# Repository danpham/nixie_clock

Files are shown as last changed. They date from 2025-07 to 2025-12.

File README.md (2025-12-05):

# Nixie Clock ESP32-C3

A **Nixie tube clock project** based on the **ESP32-C3**, using **IN14** and **IN3** tubes driven by **HV5622** high-voltage drivers.

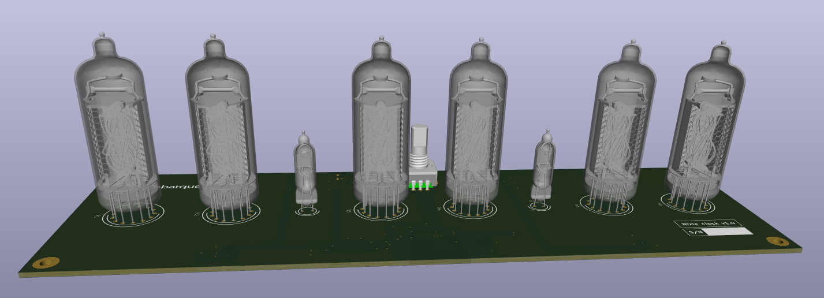
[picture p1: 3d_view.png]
3D View


## Hardware

- **Microcontroller:** ESP32-C3  
- **Nixie tubes:** 6 × IN14 and 2 × IN3  
- **Driver:** HV5622 for cathode switching  
- **Rotary encoder:** EC11 for time configuration  
- **3.3V regulator:** AP63203WU to power the ESP32-C3 and logic components  
- **PCB design:** SMD (Surface-Mount) components

> [!WARNING]
> This project involves high voltage. Follow proper electrical safety procedures!

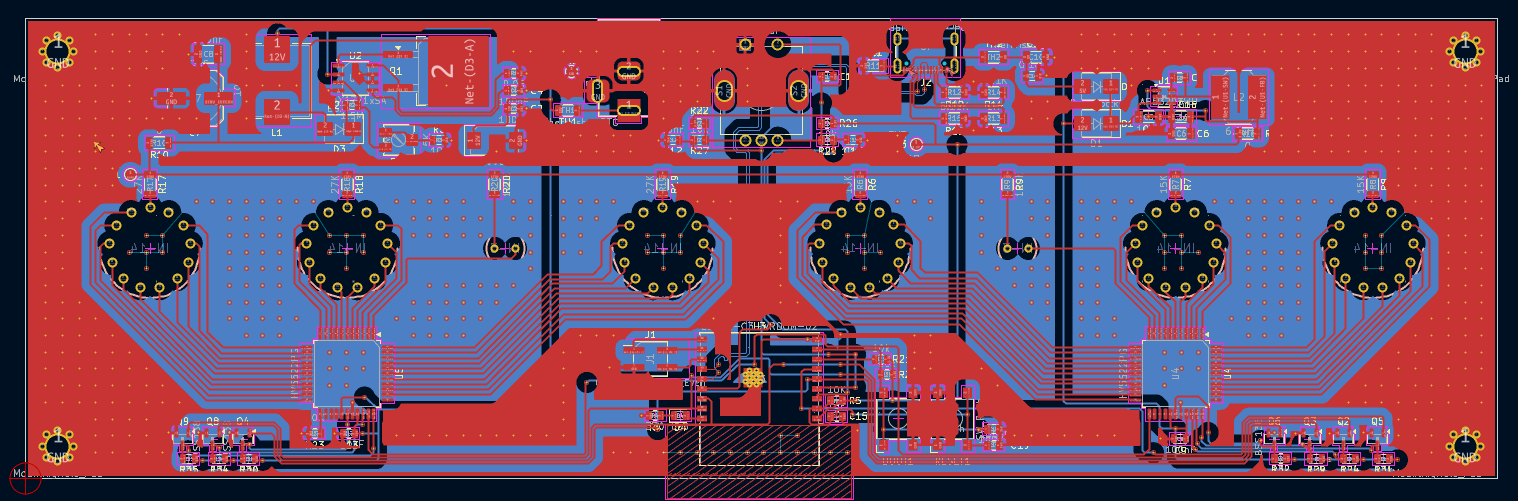
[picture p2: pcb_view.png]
PCB Back


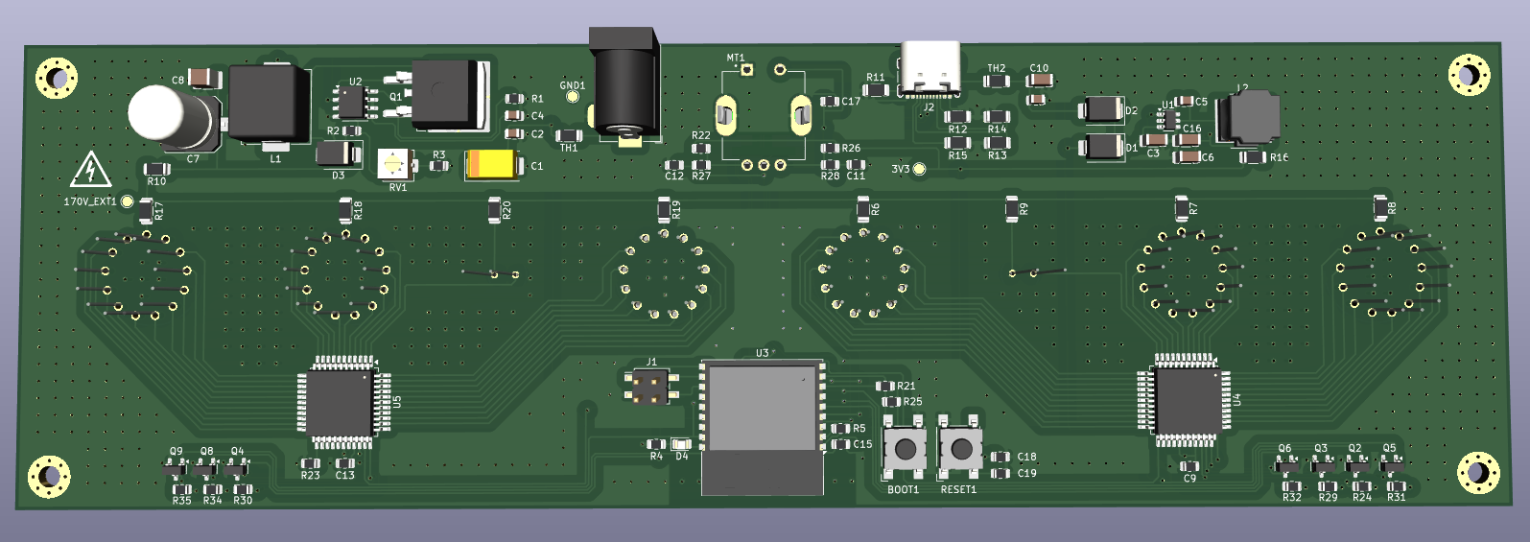
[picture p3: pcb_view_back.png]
PCB Back 3D


## Software

The code is written in **C for the ESP32-C3**, organized as follows:

```
software/nixie_clock_esp32_project/
├── components/
│   ├── uart/
│   ├── gpio_driver/
│   ├── display/
│   ├── clock/
│   └── hv5622/
└── main/
```

### Current Features

- Nixie tube display control via HV5622  
- Rotary encoder input (EC11) for setting the time  
- Internal clock management  
- **Anti–cathode poisoning routine:** periodic cycling and cathode management to prevent oxide buildup and extend tube lifespan  

### Future Features

- Wi-Fi connectivity for automatic time synchronization  
- Web interface for configuration: timezone, brightness, night mode, and display enable/disable  

## Compilation

The project uses **ESP-IDF for ESP32-C3**. Make sure your ESP32-C3 development environment is properly set up.

```bash
cd software/nixie_clock_esp32_project
idf.py build
idf.py flash
```

## Test

### Unit testing

In ESP-IDF terminal:
```bash
cd software/nixie_clock_esp32_project/test/unit
cmake -S . -B build
cmake --build build --config Release
.\build\Release\native_tests.exe
```

### Integration testing

In ESP-IDF terminal:
```bash
cd software/nixie_clock_esp32_project/test/integration
cmake -S . -B build
cmake --build build --config Release
.\build\Release\native_integration_tests.exe
```

## License

This project is released under the **GPL v3** license.  
A separate `LICENSE` file contains the complete text of the license.

## Safety

> [!WARNING]
> This project involves **high voltage (~170V for Nixie tubes)**.  
> Never touch the circuit while it is powered
> Work carefully and only with proper knowledge of high-voltage electronics

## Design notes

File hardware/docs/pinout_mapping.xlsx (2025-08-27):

Shifts | HV_* | Nixie | Data
0 | HV1_1 | N3_DOT
1 | HV1_2 | N3_0 | minute_hi
2 | HV1_3 | N3_9 | minute_hi
3 | HV1_4 | N3_8 | minute_hi
4 | HV1_5 | N3_7 | minute_hi
5 | HV1_6 | N3_6 | minute_hi
6 | HV1_7 | N3_5 | minute_hi
7 | HV1_8 | N3_4 | minute_hi
8 | HV1_9 | N3_3 | minute_hi
9 | HV1_10 | N3_2 | minute_hi
10 | HV1_11 | N3_1 | minute_hi
11 | HV1_12 | DOT1
12 | HV1_13 | N2_0 | hour_lo
13 | HV1_14 | N2_9 | hour_lo
14 | HV1_15 | N2_8 | hour_lo
15 | HV1_16 | N2_7 | hour_lo
16 | HV1_17 | N2_6 | hour_lo
17 | HV1_18 | N2_5 | hour_lo
18 | HV1_19 | N2_4 | hour_lo
19 | HV1_20 | N2_3 | hour_lo
20 | HV1_21 | N2_2 | hour_lo
21 | HV1_22 | N2_1 | hour_lo
22 | HV1_23 | N1_0 | hour_hi
23 | HV1_24 | N1_9 | hour_hi
24 | HV1_25 | N1_8 | hour_hi
25 | HV1_26 | N1_7 | hour_hi
26 | HV1_27 | N1_6 | hour_hi
27 | HV1_28 | N1_5 | hour_hi
28 | HV1_29 | N1_4 | hour_hi
29 | HV1_30 | N1_3 | hour_hi
30 | HV1_31 | N1_2 | hour_hi
31 | HV1_32 | N1_1 | hour_hi
32 | HV2_1 | N6_DOT
33 | HV2_2 | N6_0 | second_low
34 | HV2_3 | N6_9 | second_low
35 | HV2_4 | N6_8 | second_low
36 | HV2_5 | N6_7 | second_low
37 | HV2_6 | N6_6 | second_low
38 | HV2_7 | N6_5 | second_low
39 | HV2_8 | N6_4 | second_low
40 | HV2_9 | N6_3 | second_low
41 | HV2_10 | N6_2 | second_low
42 | HV2_11 | N6_1 | second_low
43 | HV2_12 | N5_0 | second_hi
44 | HV2_13 | N5_9 | second_hi
45 | HV2_14 | N5_8 | second_hi
46 | HV2_15 | N5_7 | second_hi
47 | HV2_16 | N5_6 | second_hi
48 | HV2_17 | N5_5 | second_hi
49 | HV2_18 | N5_4 | second_hi
50 | HV2_19 | N5_3 | second_hi
51 | HV2_20 | N5_2 | second_hi
52 | HV2_21 | N5_1 | second_hi
53 | HV2_22 | DOT2
54 | HV2_23 | N4_0 | minute_lo
55 | HV2_24 | N4_9 | minute_lo
56 | HV2_25 | N4_8 | minute_lo
57 | HV2_26 | N4_7 | minute_lo
58 | HV2_27 | N4_6 | minute_lo
59 | HV2_28 | N4_5 | minute_lo
60 | HV2_29 | N4_4 | minute_lo
61 | HV2_30 | N4_3 | minute_lo
62 | HV2_31 | N4_2 | minute_lo
63 | HV2_32 | N4_1 | minute_lo

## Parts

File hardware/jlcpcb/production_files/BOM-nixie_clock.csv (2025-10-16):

Comment | Designator | Footprint | LCSC | Quantity
Barrel_Jack_Switch | J7 | BarrelJack_Horizontal | C111567 | 1
1.5M | R2 | R_0805_2012Metric | C118025 | 1
100uF | C1 | CP_EIA-7343-31_Kemet-D_HandSolder | C122302 | 1
100nF | C13,C9 | R_0805_2012Metric | C126469 | 2
22uF | C16,C6 | C_1206_3216Metric | C12891 | 2
10uF | C10,C3 | C_1206_3216Metric | C13585 | 2
5.11K | R14,R15 | R_1206_3216Metric | C137249 | 2
PEC11R-4215F-S0024 | MT1 | XDCR_PEC11R-4215F-S0024 | C143790 | 1
ES2F | D3 | D_SMB | C145321 | 1
15K | R6,R7,R8 | R_1206_3216Metric | C1493 | 3
10k | R21,R22,R26,R27,R28,R5 | R_0805_2012Metric | C17414 | 6
330 | R4 | R_0805_2012Metric | C17630 | 1
0 | R10,R16 | R_1206_3216Metric | C17888 | 2
10K | R23,R25 | R_0805_2012Metric | C17902 | 2
120K | R20,R9 | R_1206_3216Metric | C17908 | 2
1M | R11,R12,R13 | R_1206_3216Metric | C17927 | 3
27K | R17,R18,R19 | R_1206_3216Metric | C17943 | 3
HV5622PG | U4,U5 | PQFP-44_10x10mm_P0.8mm | C220637 | 2
0.05 | R1 | R_0805_2012Metric | C247602 | 1
D_Schottky | D2 | D_SMB | C2479 | 1
D_Schottky | D1 | D_SMB | C2480 | 1
10k | R3 | R_0805_2012Metric | C269724 | 1
6.8uH | L2 | L_Bourns_SRN8040TA | C2849553 | 1
USB_C_Receptacle_USB2.0_16P | J2 | USB_C_Receptacle_GCT_USB4105-xx-A_16P_TopMnt_Horizontal | C2894897 | 1
ESP32-C3-WROOM-02 | U3 | ESP32-C3-WROOM-02 | C2934560 | 1
100uH | L1 | L_APV_APH1050 | C2962892 | 1
IRF740 | Q1 | TO-263-2 | C39238 | 1
0.1 uF | C14,C2,C4,C5 | C_0805_2012Metric | C396718 | 4
MAX1771xSA | U2 | SO-8_3.9x4.9mm_P1.27mm | C407903 | 1
100nF | C8 | C_1210_3225Metric_Pad1.33x2.70mm_HandSolder | C52020 | 1
Thermistor_PTC | TH1 | R_1206_3216Metric | C5678440 | 1
5K | RV1 | Potentiometer_Bourns_3314J_Vertical | C58391 | 1
AP63203WU | U1 | TSOT-23-6 | C780769 | 1
Thermistor_PTC | TH2 | R_1206_3216Metric | C883122 | 1
4.7uF | C7 | C_Elec_8x10.2 | C88702 | 1
Conn_02x02_Odd_Even | J1 | PinHeader_2x02_P2.54mm_Vertical_SMD | C919361 | 1
LED | D4 | LED_0805_2012Metric | C965812 | 1
TestPoint | GND1 | TestPoint_Pad_D1.5mm |  | 1
TestPoint | 3V3 | TestPoint_Pad_D1.5mm |  | 1
1uF | C15 | R_0805_2012Metric |  | 1
IN-14 | N6 | nixies-us-IN-14 |  | 1
IN-3 | DOT1 | nixies-us-IN-3 |  | 1
IN-14 | N3 | nixies-us-IN-14 |  | 1
IN-3 | DOT2 | nixies-us-IN-3 |  | 1
IN-14 | N1 | nixies-us-IN-14 |  | 1
IN-14 | N4 | nixies-us-IN-14 |  | 1
IN-14 | N5 | nixies-us-IN-14 |  | 1
IN-14 | N2 | nixies-us-IN-14 |  | 1
TestPoint | 170V_EXT1 | TestPoint_Pad_D1.5mm |  | 1
10nF | C12 | R_0805_2012Metric |  | 1
10nF | C11 | R_0805_2012Metric |  | 1
SW_Push | BOOT1 | SW_SPST_Omron_B3FS-100xP |  | 1
100nF | C18 | R_0805_2012Metric |  | 1
SW_Push | RESET1 | SW_SPST_Omron_B3FS-100xP |  | 1
100nf | C19 | R_0805_2012Metric |  | 1
100nF | C17 | R_0805_2012Metric |  | 1

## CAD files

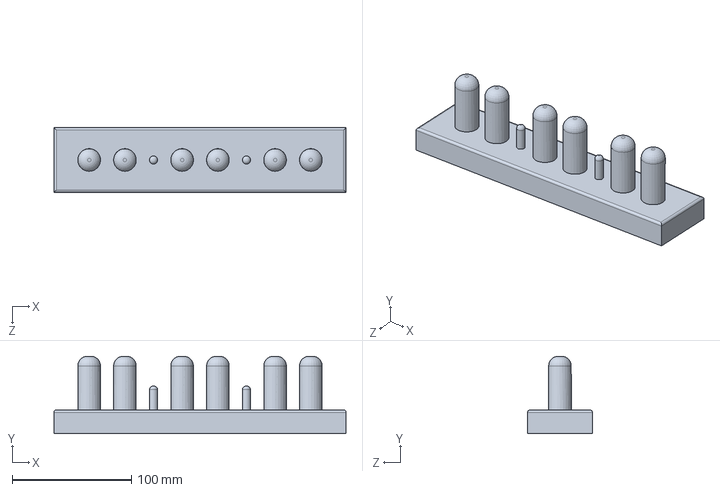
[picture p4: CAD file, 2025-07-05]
hardware/3d/nixie_clock.SLDPRT
245.0 x 65.0 x 54.3 mm

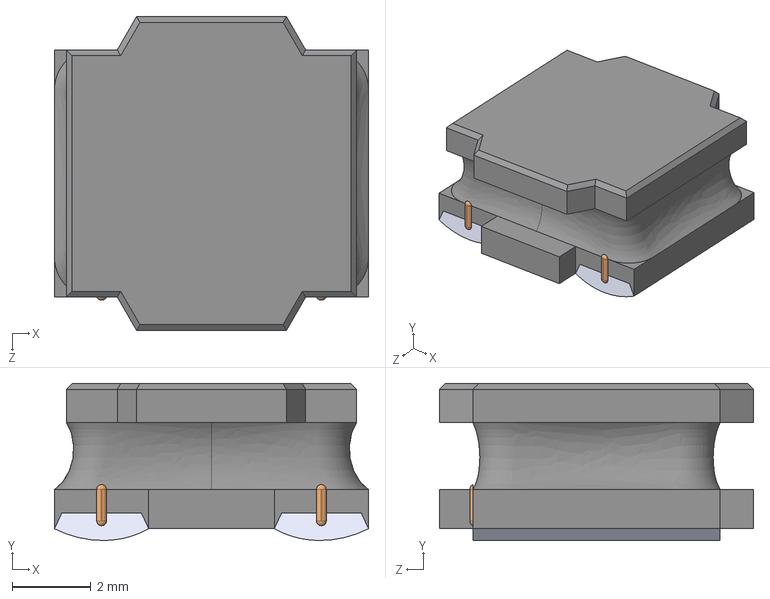
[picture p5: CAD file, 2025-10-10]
hardware/components/L_Bourns_SRN8040TA/L_Bourns_SRN8040TA.step
8.00 x 4.00 x 8.00 mm

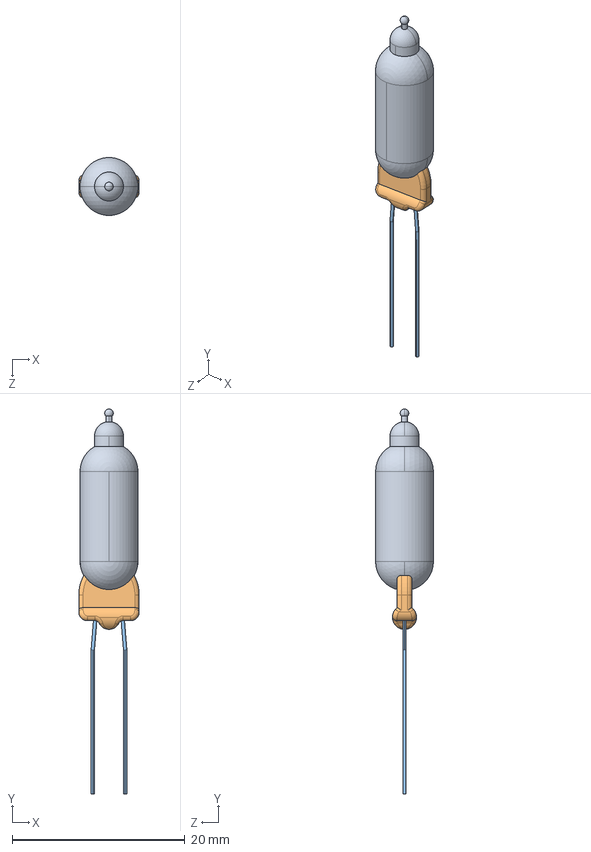
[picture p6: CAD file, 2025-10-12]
hardware/components/Nixies/NX-SZP-IN3-v01.STEP
7.00 x 44.6 x 6.70 mm
NX-SZP-IN3-01-v01
NX-SZP-IN3-02-v01 x 2
NX-SZP-IN3-03-v01
NX-SZP-IN3-04-v01
NX-SZP-IN3-05-v01
NX-SZP-IN3-06-v01

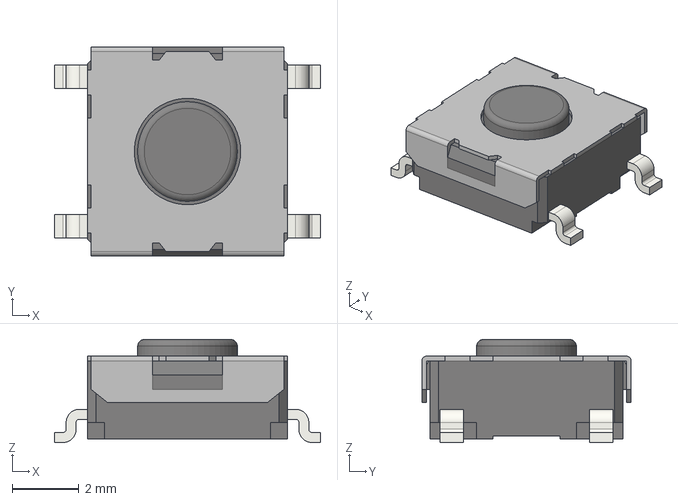
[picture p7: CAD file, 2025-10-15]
hardware/components/Omron_B3FS-1000P/SW_SPST_Omron_B3FS-100xP.step
8.00 x 6.30 x 3.10 mm

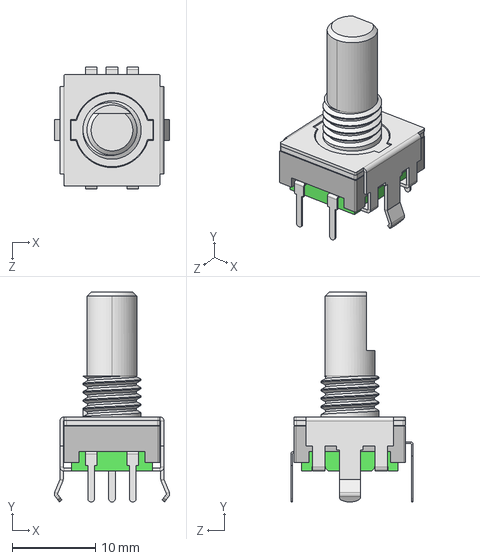
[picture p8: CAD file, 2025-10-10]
hardware/components/PEC11R-4215F-S0024/PEC11R-4215F-S0024.step
13.9 x 25.2 x 14.7 mm

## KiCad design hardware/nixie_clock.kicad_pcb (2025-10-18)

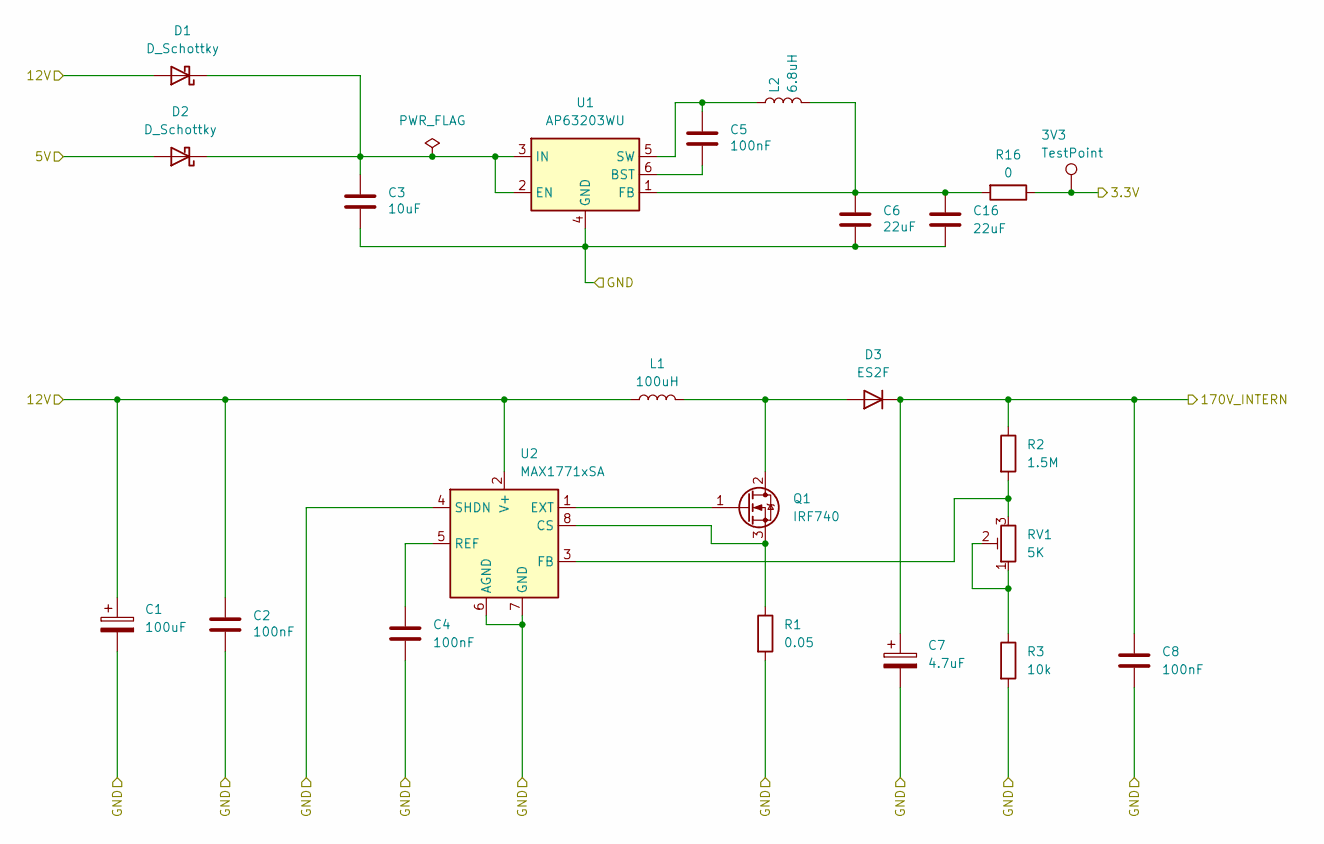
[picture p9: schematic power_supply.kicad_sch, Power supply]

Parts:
3V3: TestPoint; TestPoint_Pad_D1.5mm
C1: 100uF; CP_EIA-7343-31_Kemet-D_HandSolder
C2, C4, C5: 100nF; C_0805_2012Metric
C3: 10uF; C_1206_3216Metric
C6, C16: 22uF; C_1206_3216Metric
C7: 4.7uF; C_Elec_8x10.2
C8: 100nF; C_1210_3225Metric_Pad1.33x2.70mm_HandSolder
D1, D2: D_Schottky; D_SMB
D3: ES2F; D_SMB
L1: 100uH; L_APV_APH1050
L2: 6.8uH; L_Bourns_SRN8040TA
Q1: IRF740; TO-263-2
R1: 0.05; R_0805_2012Metric
R2: 1.5M; R_0805_2012Metric
R3: 10k; R_0805_2012Metric
R16: 0; R_1206_3216Metric
RV1: 5K; Potentiometer_Bourns_3314J_Vertical
U1: AP63203WU; TSOT-23-6
U2: MAX1771xSA; SO-8_3.9x4.9mm_P1.27mm

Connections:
/connectors/5V: D2.2 (A); also elsewhere on the board
/connectors/12V: C1.1, C2.1, D1.2 (A), L1.1, U2.2 (V+); also elsewhere on the board
/connectors/GND: C1.2, C2.2, C3.2, C4.2, C6.2, C7.2, C8.2, C16.2, R1.2, R3.2, U1.4 (GND), U2.4 (SHDN), U2.6 (AGND), U2.7 (GND); also elsewhere on the board
/cpu/3.3V: 3V3.1, R16.1; also elsewhere on the board
/driver_3_digits_1_dot_left/170V_INTERN: C7.1, C8.1, D3.1 (K), R2.1; also elsewhere on the board
unnamed: C3.1, D1.1 (K), D2.1 (K), U1.2 (EN), U1.3 (IN)
unnamed: D3.2 (A), L1.2, Q1.2 (D)
unnamed: Q1.1 (G), U2.1 (EXT)
unnamed: Q1.3 (S), R1.1, U2.8 (CS)
unnamed: R3.1, RV1.1, RV1.2
unnamed: C5.2, U1.6 (BST)
unnamed: C6.1, C16.1, L2.2, R16.2, U1.1 (FB)
unnamed: C5.1, L2.1, U1.5 (SW)
unnamed: R2.2, RV1.3, U2.3 (FB)
unnamed: C4.1, U2.5 (REF)

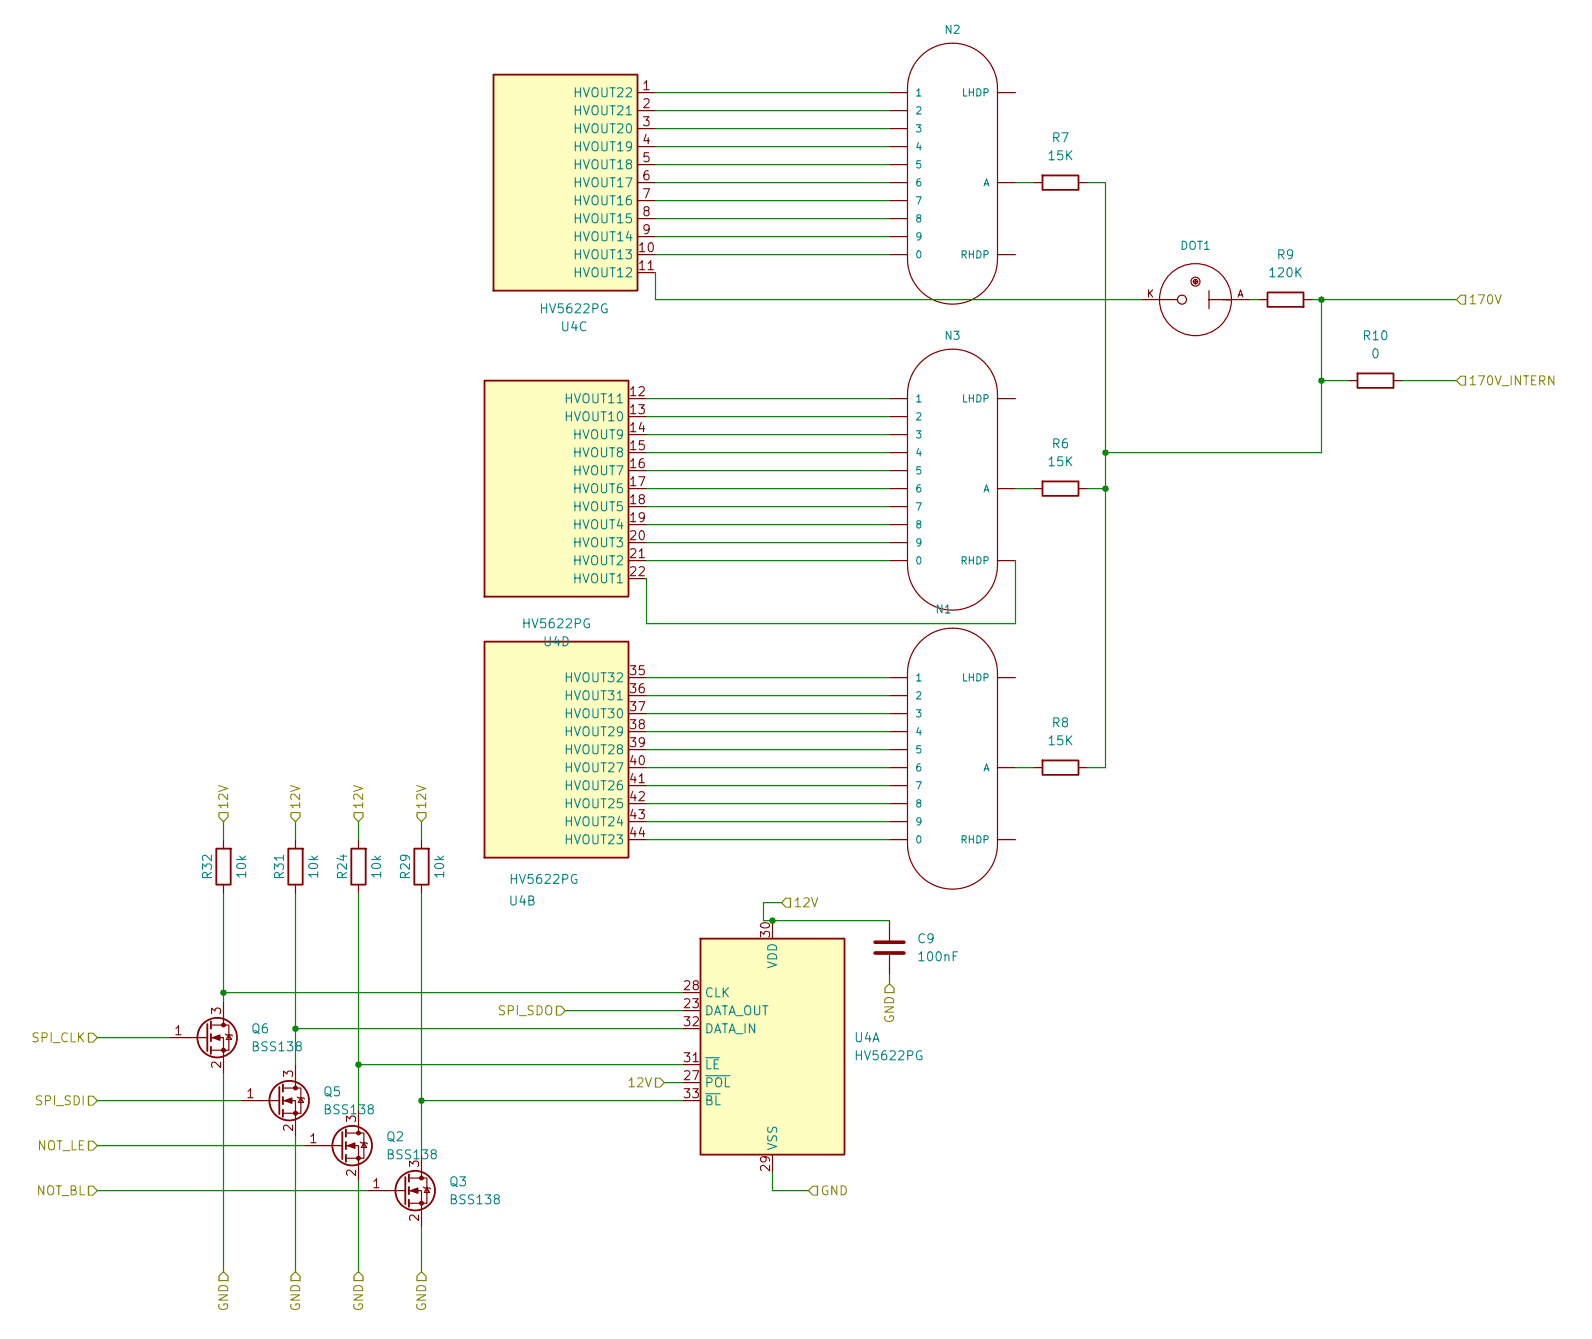
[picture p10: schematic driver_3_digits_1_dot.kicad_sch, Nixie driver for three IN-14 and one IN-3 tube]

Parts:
C9: 100nF; R_0805_2012Metric
DOT1: IN-3; nixies-us-IN-3
N1, N2, N3: IN-14; nixies-us-IN-14
Q2, Q3, Q5, Q6: BSS138; SOT-23
R6, R7, R8: 15K; R_1206_3216Metric
R9: 120K; R_1206_3216Metric
R10: 0; R_1206_3216Metric
R24, R29, R31, R32: 10k; R_0805_2012Metric
U4: HV5622PG; PQFP-44_10x10mm_P0.8mm

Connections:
/connectors/12V: C9.2, R24.2, R29.2, R31.2, R32.2, U4.27 (~POL), U4.30 (VDD); also elsewhere on the board
/connectors/170V: R6.1, R7.1, R8.1, R9.2, R10.2; also elsewhere on the board
/connectors/GND: C9.1, Q2.2 (S), Q3.2 (S), Q5.2 (S), Q6.2 (S), U4.29 (VSS); also elsewhere on the board
/cpu/GPIO1: Q3.1 (G); also elsewhere on the board
/cpu/GPIO2: Q2.1 (G); also elsewhere on the board
/cpu/SPI_CLK: Q6.1 (G); also elsewhere on the board
/cpu/SPI_MOSI: Q5.1 (G); also elsewhere on the board
/driver_3_digits_1_dot_left/170V_INTERN: R10.1; also elsewhere on the board
/driver_3_digits_1_dot_left/SPI_SDO: U4.23 (DATA_OUT); also elsewhere on the board
unnamed: DOT1.A, R9.1
unnamed: N1.A, R8.2
unnamed: N2.A, R7.2
unnamed: N3.A, R6.2
unnamed: Q2.3 (D), R24.1, U4.31 (~LE)
unnamed: Q3.3 (D), R29.1, U4.33 (~BL)
unnamed: Q5.3 (D), R31.1, U4.32 (DATA_IN)
unnamed: Q6.3 (D), R32.1, U4.28 (CLK)
unnamed: N1.0, U4.44 (HVOUT23)
unnamed: N1.9, U4.43 (HVOUT24)
unnamed: N1.8, U4.42 (HVOUT25)
unnamed: N1.7, U4.41 (HVOUT26)
unnamed: N1.6, U4.40 (HVOUT27)
unnamed: N1.5, U4.39 (HVOUT28)
unnamed: N1.4, U4.38 (HVOUT29)
unnamed: N1.3, U4.37 (HVOUT30)
unnamed: N1.2, U4.36 (HVOUT31)
unnamed: N1.1, U4.35 (HVOUT32)
unnamed: DOT1.K, U4.11 (HVOUT12)
unnamed: N2.0, U4.10 (HVOUT13)
unnamed: N2.9, U4.9 (HVOUT14)
unnamed: N2.8, U4.8 (HVOUT15)
unnamed: N2.7, U4.7 (HVOUT16)
unnamed: N2.6, U4.6 (HVOUT17)
unnamed: N2.5, U4.5 (HVOUT18)
unnamed: N2.4, U4.4 (HVOUT19)
unnamed: N2.3, U4.3 (HVOUT20)
unnamed: N2.2, U4.2 (HVOUT21)
unnamed: N2.1, U4.1 (HVOUT22)
unnamed: N3.RHDP, U4.22 (HVOUT1)
unnamed: N3.0, U4.21 (HVOUT2)
unnamed: N3.9, U4.20 (HVOUT3)
unnamed: N3.8, U4.19 (HVOUT4)
unnamed: N3.7, U4.18 (HVOUT5)
unnamed: N3.6, U4.17 (HVOUT6)
unnamed: N3.5, U4.16 (HVOUT7)
unnamed: N3.4, U4.15 (HVOUT8)
unnamed: N3.3, U4.14 (HVOUT9)
unnamed: N3.2, U4.13 (HVOUT10)
unnamed: N3.1, U4.12 (HVOUT11)

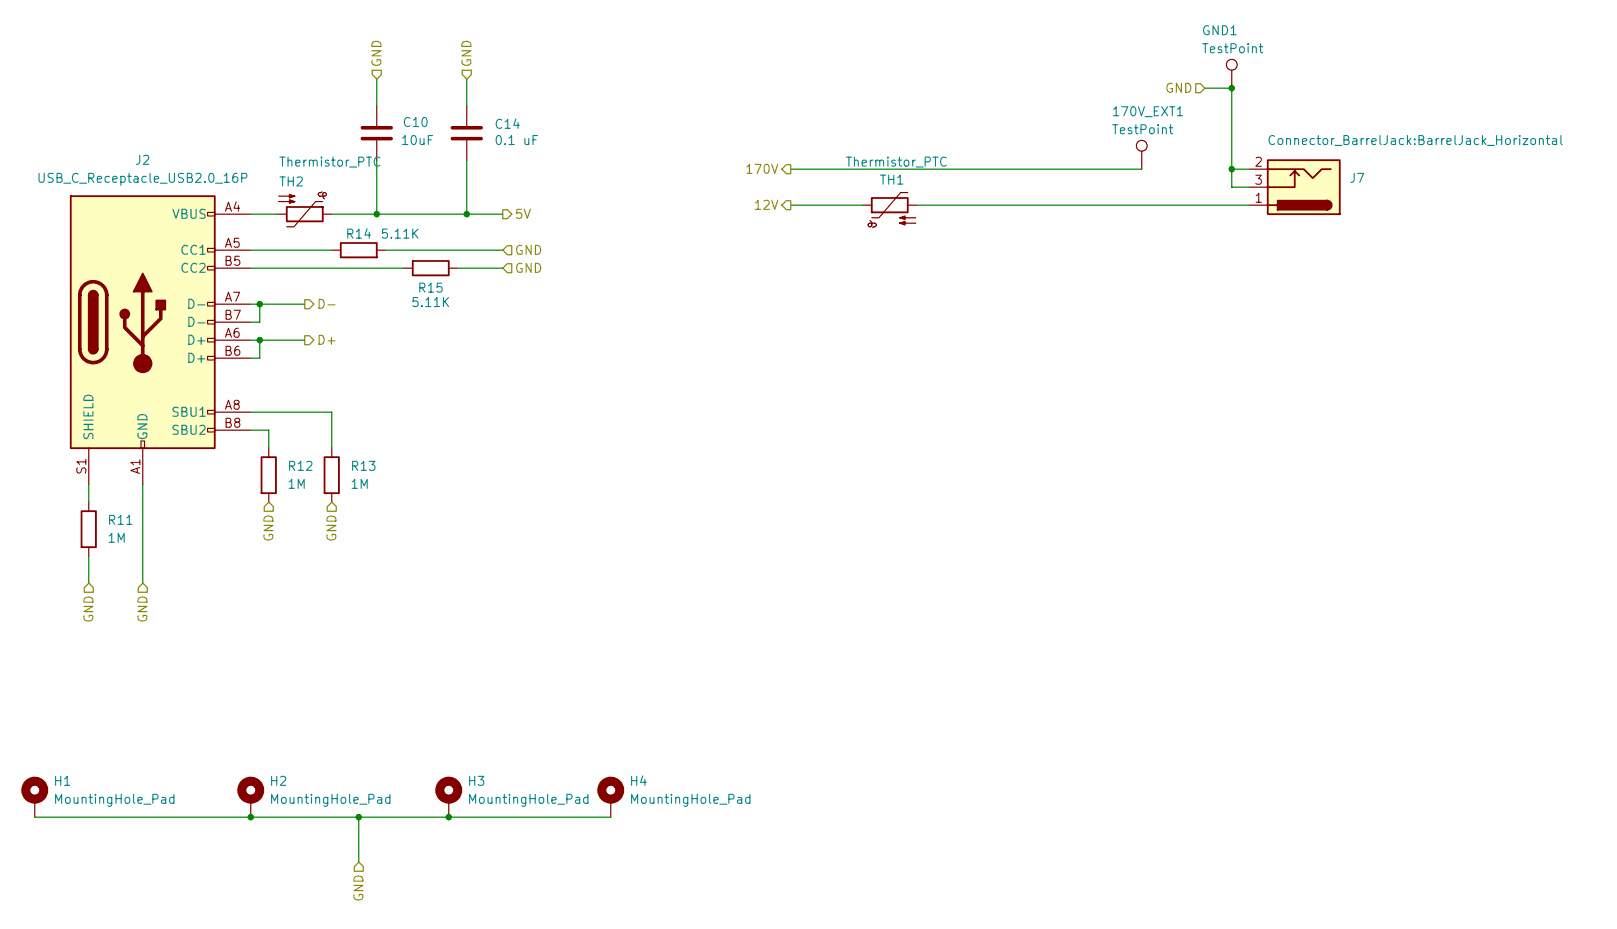
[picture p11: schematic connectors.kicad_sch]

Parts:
170V_EXT1: TestPoint; TestPoint_Pad_D1.5mm
C10: 10uF; C_1206_3216Metric
C14: 0.1 uF; C_0805_2012Metric
GND1: TestPoint; TestPoint_Pad_D1.5mm
H1, H2, H3, H4: MountingHole_Pad; MountingHole_3.2mm_M3_Pad_Via
J2: USB_C_Receptacle_USB2.0_16P; USB_C_Receptacle_GCT_USB4105-xx-A_16P_TopMnt_Horizontal
J7: Barrel_Jack_Switch; BarrelJack_Horizontal
R11, R12, R13: 1M; R_1206_3216Metric
R14, R15: 5.11K; R_1206_3216Metric
TH1, TH2: Thermistor_PTC; R_1206_3216Metric

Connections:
/connectors/5V: C10.2, C14.2, TH2.1; also elsewhere on the board
/connectors/12V: TH1.1; also elsewhere on the board
/connectors/170V: 170V_EXT1.1; also elsewhere on the board
/connectors/D+: J2.A6 (D+), J2.B6 (D+); also elsewhere on the board
/connectors/D-: J2.A7 (D-), J2.B7 (D-); also elsewhere on the board
/connectors/GND: C10.1, C14.1, GND1.1, H1.1, H2.1, H3.1, H4.1, J2.A1 (GND), J2.A12 (GND), J2.B1 (GND), J2.B12 (GND), J7.2, J7.3, R11.2, R12.2, R13.2, R14.2, R15.1; also elsewhere on the board
unnamed: J2.A5 (CC1), R14.1
unnamed: J2.B5 (CC2), R15.2
unnamed: J2.A8 (SBU1), R13.1
unnamed: J2.B8 (SBU2), R12.1
unnamed: J2.S1 (SHIELD), R11.1
unnamed: J2.A4 (VBUS), J2.A9 (VBUS), J2.B4 (VBUS), J2.B9 (VBUS), TH2.2
unnamed: J7.1, TH1.2

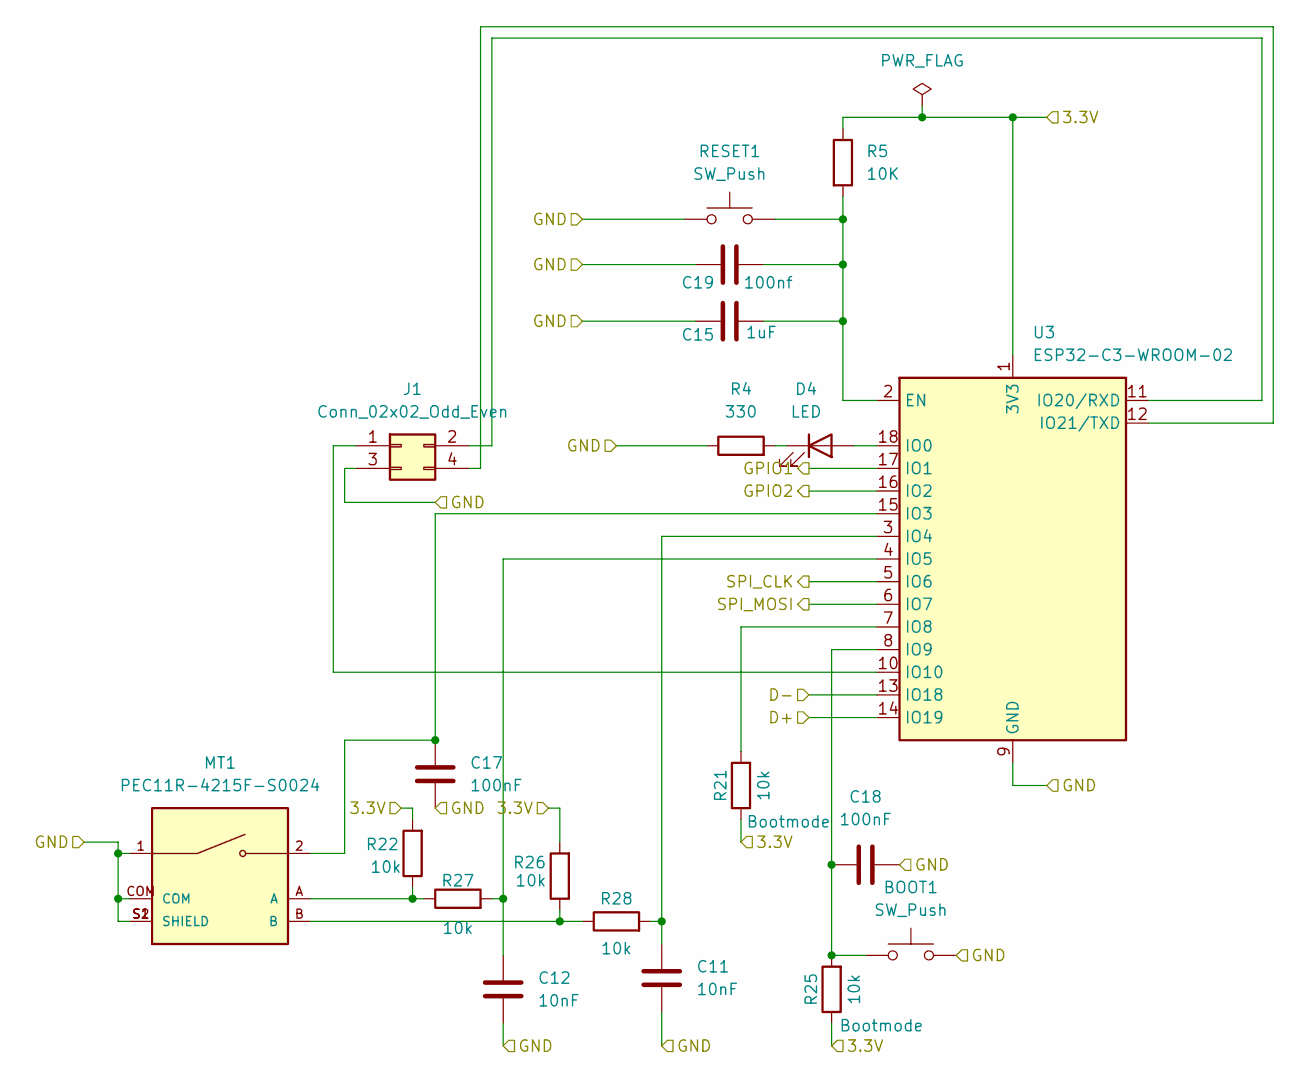
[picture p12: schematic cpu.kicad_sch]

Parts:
BOOT1: SW_Push; SW_SPST_Omron_B3FS-100xP
C11, C12: 10nF; R_0805_2012Metric
C15: 1uF; R_0805_2012Metric
C17, C18: 100nF; R_0805_2012Metric
C19: 100nf; R_0805_2012Metric
D4: LED; LED_0805_2012Metric
J1: Conn_02x02_Odd_Even; PinHeader_2x02_P2.54mm_Vertical_SMD
MT1: PEC11R-4215F-S0024; XDCR_PEC11R-4215F-S0024; PARTREV Rev. 09/19
R4: 330; R_0805_2012Metric
R5: 10K; R_0805_2012Metric
R21, R22, R25, R26, R27, R28: 10k; R_0805_2012Metric
RESET1: SW_Push; SW_SPST_Omron_B3FS-100xP
U3: ESP32-C3-WROOM-02

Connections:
/connectors/D+: U3.14 (IO19); also elsewhere on the board
/connectors/D-: U3.13 (IO18); also elsewhere on the board
/connectors/GND: BOOT1.2, C11.2, C12.2, C15.1, C17.2, C18.2, C19.1, J1.3, MT1.1, MT1.COM, MT1.S1 (SHIELD), MT1.S2 (SHIELD), R4.1, RESET1.1, U3.9 (GND), U3.19 (GND); also elsewhere on the board
/cpu/3.3V: R5.1, R21.1, R22.2, R25.1, R26.2, U3.1 (3V3); also elsewhere on the board
/cpu/GPIO1: U3.17 (IO1); also elsewhere on the board
/cpu/GPIO2: U3.16 (IO2); also elsewhere on the board
/cpu/SPI_CLK: U3.5 (IO6); also elsewhere on the board
/cpu/SPI_MOSI: U3.6 (IO7); also elsewhere on the board
unnamed: D4.2 (A), U3.18 (IO0)
unnamed: D4.1 (K), R4.2
unnamed: J1.1, U3.10 (IO10)
unnamed: J1.2, U3.11 (IO20/RXD)
unnamed: J1.4, U3.12 (IO21/TXD)
unnamed: MT1.A, R22.1, R27.1
unnamed: MT1.B, R26.1, R28.1
unnamed: C15.2, C19.2, R5.2, RESET1.2, U3.2 (EN)
unnamed: C17.1, MT1.2, U3.15 (IO3)
unnamed: C11.1, R28.2, U3.3 (IO4)
unnamed: C12.1, R27.2, U3.4 (IO5)
unnamed: R21.2, U3.7 (IO8)
unnamed: BOOT1.1, C18.1, R25.2, U3.8 (IO9)

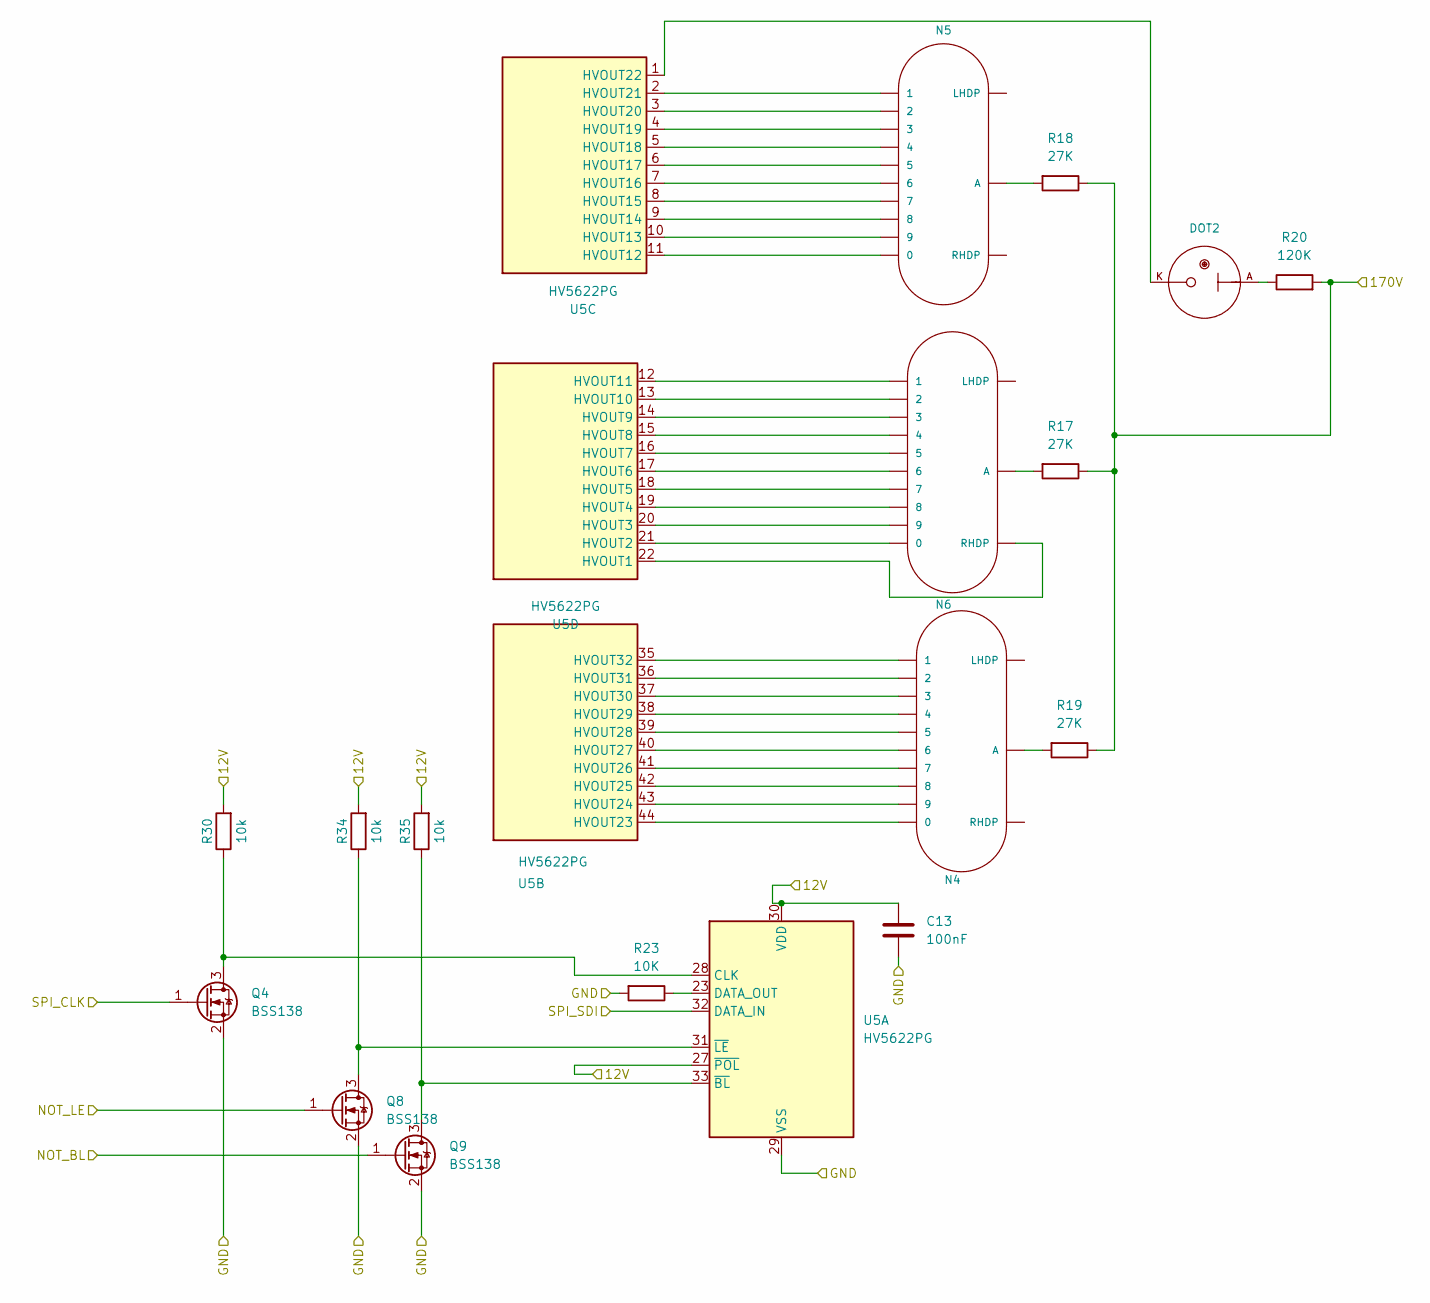
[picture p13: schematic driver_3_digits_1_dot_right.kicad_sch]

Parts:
C13: 100nF; R_0805_2012Metric
DOT2: IN-3; nixies-us-IN-3
N4, N5, N6: IN-14; nixies-us-IN-14
Q4, Q8, Q9: BSS138; SOT-23
R17, R18, R19: 27K; R_1206_3216Metric
R20: 120K; R_1206_3216Metric
R23: 10K; R_0805_2012Metric
R30, R34, R35: 10k; R_0805_2012Metric
U5: HV5622PG; PQFP-44_10x10mm_P0.8mm

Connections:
/connectors/12V: C13.2, R30.2, R34.2, R35.2, U5.27 (~POL), U5.30 (VDD); also elsewhere on the board
/connectors/170V: R17.1, R18.1, R19.1, R20.2; also elsewhere on the board
/connectors/GND: C13.1, Q4.2 (S), Q8.2 (S), Q9.2 (S), R23.2, U5.29 (VSS); also elsewhere on the board
/cpu/GPIO1: Q9.1 (G); also elsewhere on the board
/cpu/GPIO2: Q8.1 (G); also elsewhere on the board
/cpu/SPI_CLK: Q4.1 (G); also elsewhere on the board
/driver_3_digits_1_dot_left/SPI_SDO: U5.32 (DATA_IN); also elsewhere on the board
unnamed: DOT2.A, R20.1
unnamed: N4.A, R19.2
unnamed: N5.A, R18.2
unnamed: N6.A, R17.2
unnamed: Q4.3 (D), R30.1, U5.28 (CLK)
unnamed: Q8.3 (D), R34.1, U5.31 (~LE)
unnamed: Q9.3 (D), R35.1, U5.33 (~BL)
unnamed: R23.1, U5.23 (DATA_OUT)
unnamed: N4.0, U5.44 (HVOUT23)
unnamed: N4.9, U5.43 (HVOUT24)
unnamed: N4.8, U5.42 (HVOUT25)
unnamed: N4.7, U5.41 (HVOUT26)
unnamed: N4.6, U5.40 (HVOUT27)
unnamed: N4.5, U5.39 (HVOUT28)
unnamed: N4.4, U5.38 (HVOUT29)
unnamed: N4.3, U5.37 (HVOUT30)
unnamed: N4.2, U5.36 (HVOUT31)
unnamed: N4.1, U5.35 (HVOUT32)
unnamed: N5.0, U5.11 (HVOUT12)
unnamed: N5.9, U5.10 (HVOUT13)
unnamed: N5.8, U5.9 (HVOUT14)
unnamed: N5.7, U5.8 (HVOUT15)
unnamed: N5.6, U5.7 (HVOUT16)
unnamed: N5.5, U5.6 (HVOUT17)
unnamed: N5.4, U5.5 (HVOUT18)
unnamed: N5.3, U5.4 (HVOUT19)
unnamed: N5.2, U5.3 (HVOUT20)
unnamed: N5.1, U5.2 (HVOUT21)
unnamed: DOT2.K, U5.1 (HVOUT22)
unnamed: N6.RHDP, U5.22 (HVOUT1)
unnamed: N6.0, U5.21 (HVOUT2)
unnamed: N6.9, U5.20 (HVOUT3)
unnamed: N6.8, U5.19 (HVOUT4)
unnamed: N6.7, U5.18 (HVOUT5)
unnamed: N6.6, U5.17 (HVOUT6)
unnamed: N6.5, U5.16 (HVOUT7)
unnamed: N6.4, U5.15 (HVOUT8)
unnamed: N6.3, U5.14 (HVOUT9)
unnamed: N6.2, U5.13 (HVOUT10)
unnamed: N6.1, U5.12 (HVOUT11)

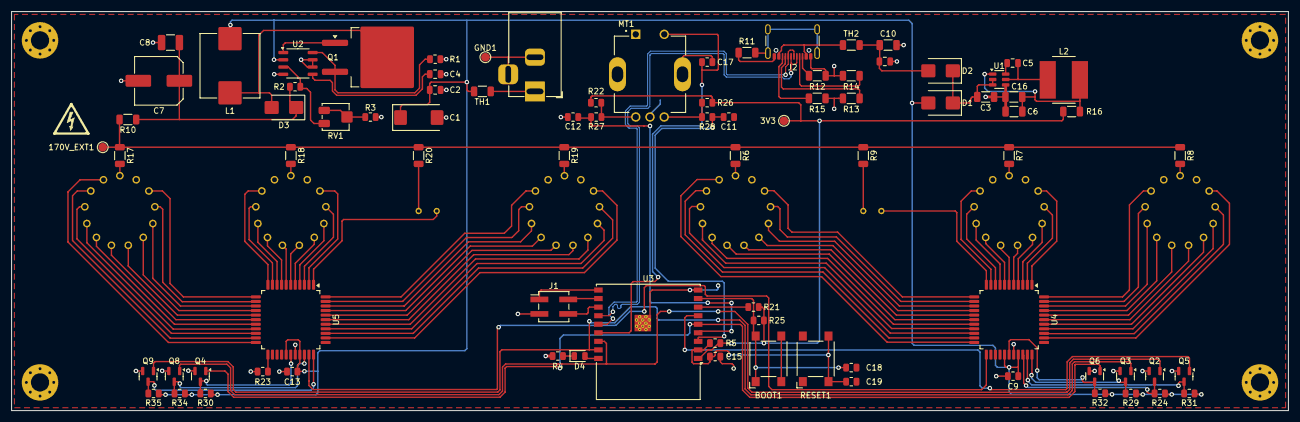
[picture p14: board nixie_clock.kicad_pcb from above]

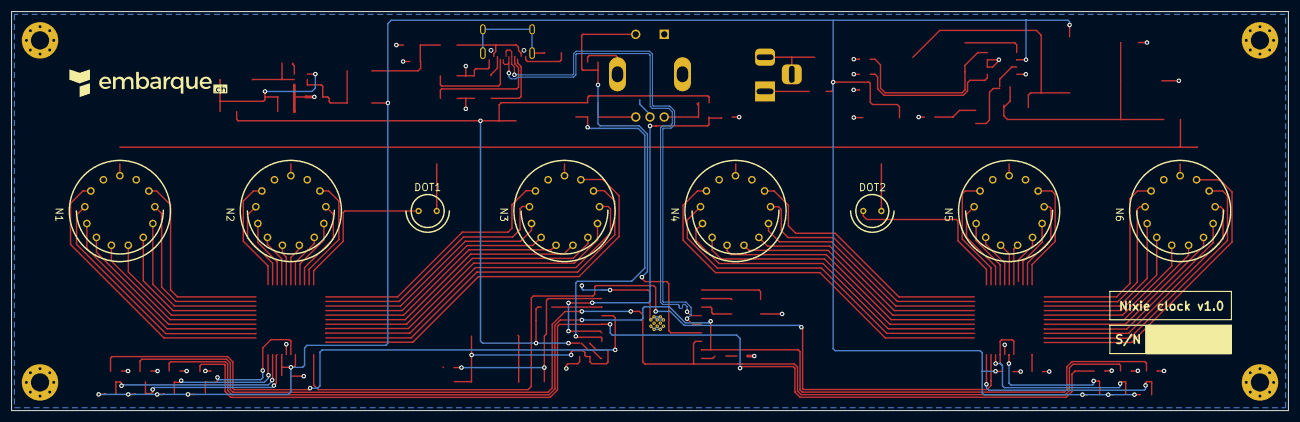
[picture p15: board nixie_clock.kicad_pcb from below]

Board: 2 copper layers, 224.0 x 70.0 mm, 96 parts (8 on the bottom side), 123 nets.

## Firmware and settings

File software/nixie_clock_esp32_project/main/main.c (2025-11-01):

/******************************************************************
 * 1. Included files (microcontroller ones then user defined ones)
******************************************************************/
#include <string.h>
#include "driver/gpio.h"
#include "gpio_task.h"
#include "clock_task.h"
#include "../components/uart/uart.h"
#include "../components/hv5622/hv5622.h"
#include "../components/display/display.h"
#include "../components/clock/clock.h"


/******************************************************************
 * 2. Define declarations (macros then function macros)
******************************************************************/


/******************************************************************
 * 3. Typedef definitions (simple typedef, then enum and structs)
******************************************************************/


/******************************************************************
 * 4. Variable definitions (static then global)
******************************************************************/


/******************************************************************
 * 5. Functions prototypes (static only)
******************************************************************/


/******************************************************************
 * 6. Functions definitions
******************************************************************/
void app_main(void);

/* MISRA C:2012 Rule 8.9 deviation:
   app_main() is called externally by FreeRTOS/ESP-IDF runtime */
// cppcheck-suppress unusedFunction
void app_main(void)
{
    const char hello[] = "Nixie clock v1.0: Starting...";
    size_t len = sizeof(hello) - 1U;

    uart_init();
    uart_write(hello, len);

    hv5622_init();
    display_init();

    clock_task_start();
    gpio_task_start();

    while(1) {
        vTaskDelay(pdMS_TO_TICKS(1000)); // Main loop remains free
    }
}

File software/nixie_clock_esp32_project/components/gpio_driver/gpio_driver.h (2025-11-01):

#pragma once
#include "driver/gpio.h"
#include "esp_err.h"

#define BUTTON_LONG_PRESS_MS 2000U

typedef enum {
    BUTTON_STATE_RELEASE  = 0,
    BUTTON_STATE_PRESS = 1
} button_state_t;

typedef enum {
    BUTTON_SHORT_PRESS = 0,
    BUTTON_LONG_PRESS  = 1
} button_press_t;

// Pull-up / Pull-down enum
typedef enum {
    MY_GPIO_PULL_NONE,
    MY_GPIO_PULL_UP,
    MY_GPIO_PULL_DOWN
} my_gpio_pull_t;

// Button structure with debounce
typedef struct {
    gpio_num_t pin;
    my_gpio_pull_t pull;
    button_state_t last_state;
    button_press_t press_type;
    uint32_t last_change_ms;
    uint32_t press_start_ms;
    uint32_t debounce_ms;
} my_gpio_btn_t;

// GPIO functions
esp_err_t my_gpio_init(my_gpio_btn_t *btn);
int my_gpio_read_btn(my_gpio_btn_t *btn);

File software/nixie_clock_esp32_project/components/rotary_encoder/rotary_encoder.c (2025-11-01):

/******************************************************************
 * 1. Included files (microcontroller ones then user defined ones)
******************************************************************/
#include <stdint.h>
#include "rotary_encoder.h"

/******************************************************************
 * 2. Define declarations (macros then function macros)
******************************************************************/

/******************************************************************
 * 3. Typedef definitions (simple typedef, then enum and structs)
******************************************************************/

/******************************************************************
 * 4. Variable definitions (static then global)
******************************************************************/

/******************************************************************
 * 5. Functions prototypes (static only)
******************************************************************/

/**
 * @brief Calculates the rotary encoder event
 * @param lastA Last state of channel A (0 or 1)
 * @param lastB Last state of channel B (0 or 1)
 * @param currentA Current state of channel A (0 or 1)
 * @param currentB Current state of channel B (0 or 1)
 * @return The corresponding event (increment, decrement, or none)
 */
rotary_encoder_event_t process_rotary_encoder(uint8_t lastA, uint8_t lastB, uint8_t currentA, uint8_t currentB)
{
    int8_t lastCode = 0;
    int8_t currentCode = 0;
    /* Transition table : lastCode -> currentCode 
      +1 = clockwise, -1 = counterclockwise, 0 = no movement */
    static const int8_t transition_table[4][4] = {
        {  0, -1, +1,  0 },
        { +1,  0,  0, -1 },
        { -1,  0,  0, +1 },
        {  0, +1, -1,  0 }
    };
    
    rotary_encoder_event_t ret = ROTARY_ENCODER_EVENT_NONE;

    /* Encode states into 0..3 */
    lastCode = (lastA << 1) | lastB;
    currentCode = (currentA << 1) | currentB;

    /* Safety check: indices must be 0..3 */
    if ((lastCode < 0) || (lastCode > 3) || (currentCode < 0) || (currentCode > 3)) {
        ret = ROTARY_ENCODER_EVENT_NONE;
    }
    else
    {
        int8_t direction = 0;
        direction = transition_table[lastCode][currentCode];
        
        if (direction > 0) {
          ret = ROTARY_ENCODER_EVENT_INCREMENT;
        }
        else if (direction < 0) {
          ret = ROTARY_ENCODER_EVENT_DECREMENT;
        }
        else {
          ret = ROTARY_ENCODER_EVENT_NONE;
        }
    }

    return ret;
}

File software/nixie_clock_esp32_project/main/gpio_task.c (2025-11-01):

/******************************************************************
 * 1. Included files (microcontroller ones then user defined ones)
******************************************************************/
#include "freertos/FreeRTOS.h"
#include "freertos/task.h"
#include "gpio_task.h"
#include "../components/gpio_driver/gpio_driver.h"
#include "../components/rotary_encoder/rotary_encoder.h"
#include "esp_log.h"
#include "esp_stub.h"

/******************************************************************
 * 2. Define declarations (macros then function macros)
******************************************************************/

/******************************************************************
 * 3. Typedef definitions (simple typedef, then enum and structs)
******************************************************************/

/******************************************************************
 * 4. Variable definitions (static then global)
******************************************************************/
QueueHandle_t buttonQueue;

/******************************************************************
 * 5. Functions prototypes (static only)
******************************************************************/
static void gpio_task(void *arg);

/******************************************************************
 * 6. Functions definitions
******************************************************************/

static void gpio_task(void *arg)
{
    const char *TAG = "GPIO_TASK";
    (void)arg;

    my_gpio_btn_t rotaryEncoderSwitch = {
        .pin = GPIO_NUM_3,
        .pull = MY_GPIO_PULL_NONE,
        .debounce_ms = 50
    };

    my_gpio_btn_t rotaryEncoderChanB = {
        .pin = GPIO_NUM_4,
        .pull = MY_GPIO_PULL_NONE,
        .debounce_ms = 50
    };

    my_gpio_btn_t rotaryEncoderChanA = {
        .pin = GPIO_NUM_5,
        .pull = MY_GPIO_PULL_NONE,
        .debounce_ms = 50
    };
    button_event_t event;
    int8_t state_last_rotaryChanA = 0;
    int8_t state_last_rotaryChanB = 0;
    button_state_t state_last_rotarySwitch = 0;
 
    if (my_gpio_init(&rotaryEncoderSwitch) != ESP_OK) {
        ESP_LOGE(TAG, "Failed to initialize rotaryEncoderSwitch!");
    }

    if (my_gpio_init(&rotaryEncoderChanA) != ESP_OK) {
        ESP_LOGE(TAG, "Failed to initialize rotaryEncoderChanA!");
    }

    if (my_gpio_init(&rotaryEncoderChanB) != ESP_OK) {
        ESP_LOGE(TAG, "Failed to initialize rotaryEncoderChanB!");
    }

    /* Initialize state_last_ variables */
    state_last_rotaryChanA = (int8_t)my_gpio_read_btn(&rotaryEncoderChanA);
    state_last_rotaryChanB = (int8_t)my_gpio_read_btn(&rotaryEncoderChanB);
    state_last_rotarySwitch = (int8_t)my_gpio_read_btn(&rotaryEncoderSwitch);

    while(1) {
        button_state_t state_rotarySwitch = 0;
        int8_t state_rotaryChanA = 0;
   
        state_rotarySwitch = (int8_t)my_gpio_read_btn(&rotaryEncoderSwitch);

        /* Avoid sending event when no changes */
        if (state_last_rotarySwitch != state_rotarySwitch){
            if (state_rotarySwitch == (button_state_t)BUTTON_STATE_PRESS) {
                event.id = (buttons_type_t)BUTTON_ROTARY_SWITCH_1;
                event.pressed = rotaryEncoderSwitch.press_type;
                xQueueSend(buttonQueue, &event, 0);
                ESP_LOGI(TAG, "Rotary switch pressed!");
            } else {
                event.id = (buttons_type_t)BUTTON_ROTARY_SWITCH_1;
                event.pressed = rotaryEncoderSwitch.press_type;
                xQueueSend(buttonQueue, &event, 0);
                ESP_LOGI(TAG, "Rotary switch released");
            }
            state_last_rotarySwitch = state_rotarySwitch;
        }

        state_rotaryChanA = (int8_t)my_gpio_read_btn(&rotaryEncoderChanA);
        int8_t state_rotaryChanB = (int8_t)my_gpio_read_btn(&rotaryEncoderChanB);
        rotary_encoder_event_t ev = process_rotary_encoder(state_last_rotaryChanA, state_last_rotaryChanB, state_rotaryChanA, state_rotaryChanB);
        if (ev != ROTARY_ENCODER_EVENT_NONE) {
            event.id = (buttons_type_t)BUTTON_ROTARY_ENCODER;
            event.updateValue = (uint8_t)ev;
            xQueueSend(buttonQueue, &event, 0);
            ESP_LOGI(TAG, "Rotary encoder %s", (ev == ROTARY_ENCODER_EVENT_INCREMENT) ? "increment" : "decrement");
        }

        state_last_rotaryChanA = state_rotaryChanA;
        state_last_rotaryChanB = state_rotaryChanB;

        vTaskDelay(pdMS_TO_TICKS(5)); // Loop every 5 ms
    }
}
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

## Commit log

2025-06-17 Initial commit.
    [connectors.kicad_sch, cpu.kicad_sch, driver_3_digits_1_dot.kicad_sch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]
2025-06-21 First routage.
    [cpu.kicad_sch, driver_3_digits_1_dot_right.kicad_sch, nixie_clock.kicad_pcb]
2025-06-22 Update vias.
    [connectors.kicad_sch, nixie_clock.kicad_pcb]
2025-06-23 Add buttons.
    [connectors.kicad_sch, cpu.kicad_sch, nixie_clock.kicad_pcb]
2025-06-23 Add HT psu.
    [connectors.kicad_sch, cpu.kicad_sch, driver_3_digits_1_dot.kicad_sch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]
2025-06-26 Add holes with via. Avoid too long tracks.
    [connectors.kicad_sch, nixie_clock.kicad_pcb, power_supply.kicad_sch]
2025-07-06 Rename nixie's names to have the right order.
    [driver_3_digits_1_dot.kicad_sch, driver_3_digits_1_dot_right.kicad_sch, nixie_clock.kicad_pcb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]
2025-07-06 Change power connector.
    [connectors.kicad_sch, nixie_clock.kicad_pcb]
2025-08-17 Rework some tracks.
    [nixie_clock.kicad_pcb]
2025-08-17 Fix USB lane size.
    [nixie_clock.kicad_pcb]
2025-08-17 Fix DRC errors.
    [nixie_clock.kicad_pcb, power_supply.kicad_sch]
2025-08-18 Add clearance of 0.8mm on HV lines for every nixie tube.
    [nixie_clock.kicad_pcb]
2025-08-18 Add space arround C13.
    [nixie_clock.kicad_pcb]
2025-08-18 Add decoupling capacitor for MCU. Fix circuit to avoid VCC being between capacitor and power pad.
    [cpu.kicad_sch, nixie_clock.kicad_pcb]
2025-08-18 Rework C9. Placed closer to the power pad.
    [nixie_clock.kicad_pcb]
2025-08-20 Remove POLarity setup, needs 12V to be not reversed.
    [driver_3_digits_1_dot.kicad_sch, driver_3_digits_1_dot_right.kicad_sch, nixie_clock.kicad_pcb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]
2025-08-20 Fix DRC erros.
    [nixie_clock.kicad_pcb]
2025-08-21 C15, C13, C9 changed to 805 form factor. Removed tracks under capacitors.
    [cpu.kicad_sch, driver_3_digits_1_dot.kicad_sch, driver_3_digits_1_dot_right.kicad_sch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]
2025-08-21 Update D4 and R4 to 805 size.
    [cpu.kicad_sch, nixie_clock.kicad_pcb]
2025-08-21 Fix tube resistors and capacitors with 805.
    [power_supply.kicad_sch]
2025-08-23 Rework 3.3v power supply (fix error on fb loop). Put 1206 back on HV part.
    [connectors.kicad_sch, cpu.kicad_sch, driver_3_digits_1_dot.kicad_sch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]
2025-08-24 Fix most of ERC on schema. Add missing wire on RV1. Add PWR_FLG on GND to avoid error. Add resistor for unused SPI_OUT of HV5622. Add PTC on 3v3 supply.
    [connectors.kicad_sch, driver_3_digits_1_dot.kicad_sch, driver_3_digits_1_dot_right.kicad_sch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]
2025-08-25 Add pull down resistors for non used pins.
    [cpu.kicad_sch, nixie_clock.kicad_pcb]
2025-08-25 Remove DRC error.
    [nixie_clock.kicad_pcb]
2025-08-25 Add serial on silkscren.
    [nixie_clock.kicad_pcb]
2025-08-25 Correct centering of nixies on the board.
    [driver_3_digits_1_dot.kicad_sch, nixie_clock.kicad_pcb]
2025-08-25 Tweak USB.
    [nixie_clock.kicad_pcb]
2025-08-27 Add button handling.
2025-08-27 Update PCB.
    [connectors.kicad_sch, nixie_clock.kicad_pcb, power_supply.kicad_sch]
2025-08-27 Add pinout mapping. Update display software.
    [pinout_mapping.xlsx]
2025-08-28 Update 2 vias. Update settings.json.
    [nixie_clock.kicad_pcb]
2025-08-29 Replace input with 12V barrel connector. Add test point for alternative 170V input.
    [connectors.kicad_sch, nixie_clock.kicad_pcb]
2025-08-29 Rework HT PSU placement.
    [connectors.kicad_sch, nixie_clock.kicad_pcb, power_supply.kicad_sch]
2025-08-30 Center USB-C connector on PCB. Add testpoints.
    [connectors.kicad_sch, nixie_clock.kicad_pcb, power_supply.kicad_sch]
2025-09-04 Add embarque logo as library.
    [embarque-logo-full.dxf, nixie_clock.kicad_pcb]
2025-09-04 Remove .dxf file, useless.
    [embarque-logo-full.dxf]
2025-09-05 Update components to match BOM.
    [bom.xlsx, nixie_clock.kicad_pcb, power_supply.kicad_sch]
2025-09-06 Add dot ch logo.
    [nixie_clock.kicad_pcb]
2025-09-10 Remove HV capacitor for Nixies. Add more LCSC references.
    [connectors.kicad_sch, cpu.kicad_sch, driver_3_digits_1_dot.kicad_sch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]
2025-09-30 Limitate inrush current (decoupling capacitors after PTCs). Add decoupling capacitors for VUSB.
    [connectors.kicad_sch, nixie_clock.kicad_pcb, power_supply.kicad_sch]
2025-09-30 Revert GND layer to original position.
    [nixie_clock.kicad_pcb]
2025-09-30 Update, DRC ok.
    [nixie_clock.kicad_pcb, power_supply.kicad_sch]
2025-09-30 Add 3314J potentiometer. Found L2 LCSC part number.
    [nixie_clock.kicad_pcb, power_supply.kicad_sch]
2025-10-10 Add PEC11 encoder instead of pushbuttons switches.
    [cpu.kicad_sch, nixie_clock.kicad_pcb]
2025-10-10 Change to path on 3V3 Testpoint.
    [cpu.kicad_sch, nixie_clock.kicad_pcb]
2025-10-10 Add external components. Add BOM and CPL.
    [BOM-nixie_clock.csv, L_Bourns_SRN8040TA.step, PEC11R-4215F-S0024.step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]
2025-10-10 Rework track.
    [nixie_clock.kicad_pcb]
2025-10-10 Add capacitor for rotary switch.
    [BOM-nixie_clock.csv, cpu.kicad_sch, nixie_clock.kicad_pcb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]
2025-10-12 Add IO1 to pin header. Add .step models.
    [NX-SZP-IN3-v01.STEP, cpu.kicad_sch, nixie_clock.kicad_pcb]
2025-10-12 Add rotary encoder.
2025-10-12 Add via stitching.
    [nixie_clock.kicad_pcb]
2025-10-12 Update components paths for Misra checks. Fix Misra errors.
    [gpio_driver.c]
2025-10-12 MISRA fix 6. Add UART output.
    [main.c]
2025-10-14 Remove useless 10k resistor for PEC11 switch.
    [cpu.kicad_sch, nixie_clock.kicad_pcb]
2025-10-15 Add BOOT1 and RESET1 buttons. Add pullups on Boot strapping pins GPIO8,9. Fix EN, enable input.
    [SW_SPST_Omron_B3FS-100xP.step, cpu.kicad_sch, nixie_clock.kicad_pcb]
2025-10-15 Add images to README for project visualization
    Added images of the 3D view and PCB view to README.
2025-10-15 Update README to remove duplicate image
    Removed duplicate PCB view image and adjusted formatting.
2025-10-16 Removed useless vias.
    [nixie_clock.kicad_pcb]
2025-10-16 Remap /LE and /BL to GPIO2 and GPIO1. SPI2 clk to GPIO6, SPI2 data to GPIO7.
    [cpu.kicad_sch, nixie_clock.kicad_pcb]
2025-10-16 Add high voltage symbol.
    [BOM-nixie_clock.csv, nixie_clock.kicad_pcb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]
2025-10-16 Re-route GPIO1, 2 that were missing.
    [nixie_clock.kicad_pcb]
2025-10-16 Use PCB cleanup tool from Kicad.
    [nixie_clock.kicad_pcb]
2025-10-17 Add mosfets for handling levels.
    [driver_3_digits_1_dot.kicad_sch, driver_3_digits_1_dot_right.kicad_sch, nixie_clock.kicad_pcb]
2025-10-17 Route conversion level mosfets.
    [nixie_clock.kicad_pcb]
2025-10-17 Cleanup vias and tracks.
    [nixie_clock.kicad_pcb]
2025-10-17 Rework text positions.
    [nixie_clock.kicad_pcb]
2025-10-17 Remove one mosfet on the right since SPI out from the first HV5622 is already on 12v level.
    [driver_3_digits_1_dot_right.kicad_sch, nixie_clock.kicad_pcb]
2025-10-17 Making tracks to mosfets shorter.
    [nixie_clock.kicad_pcb]
2025-10-18 Remove one via near HV5622. Tweaks.
    [nixie_clock.kicad_pcb]
2025-10-18 Remove one unused track.
    [nixie_clock.kicad_pcb]
2025-10-18 Modify code to invert data due to mosfets.
    [hv5622.c]
2025-10-18 Simplify 12V rail on U5.
    [nixie_clock.kicad_pcb]
2025-10-18 Correct track near U5.
    [nixie_clock.kicad_pcb]
2025-10-18 Increase text size for Nixies and dots silkscreen. Fix solder mask opening error on JLPCB DFM. Correct one warning distance to pad on mosfets.
    [nixie_clock.kicad_pcb]
2025-10-18 Correct N3 placement.
    [nixie_clock.kicad_pcb]
2025-10-21 Add rotary encoder unit tests.
2025-10-22 Add quadrature support for rotary encoder. Update rotary encoder unit test.
2025-11-01 Fix MISRA errors. Add MISRA check to GitHub Actions.
    [clock_task.c, gpio_driver.c]
2025-11-01 Fix tests after Misra changes. Correct a regression in rotary_encoder.c.
    [rotary_encoder.c]
2025-12-05 Revise high voltage warning formatting in README
    Updated warning format for high voltage safety in README.

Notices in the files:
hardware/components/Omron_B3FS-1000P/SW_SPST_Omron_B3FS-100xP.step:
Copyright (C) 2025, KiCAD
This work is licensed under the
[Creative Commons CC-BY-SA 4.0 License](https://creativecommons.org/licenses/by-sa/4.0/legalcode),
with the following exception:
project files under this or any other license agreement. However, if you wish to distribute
